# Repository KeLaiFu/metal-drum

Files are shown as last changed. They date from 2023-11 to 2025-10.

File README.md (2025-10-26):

This is a clone of a well known drum module, it has been tested, and with a few fixes, works fine.
The main issue is the transistors are 'flipped', this is due to the pin numbering being different between the THT and SMD versions within kicad. You can fix this by turning the transistor over and fitting it upside down. Theres one j111X component which doesnt have this problem and should be fitted as normal.

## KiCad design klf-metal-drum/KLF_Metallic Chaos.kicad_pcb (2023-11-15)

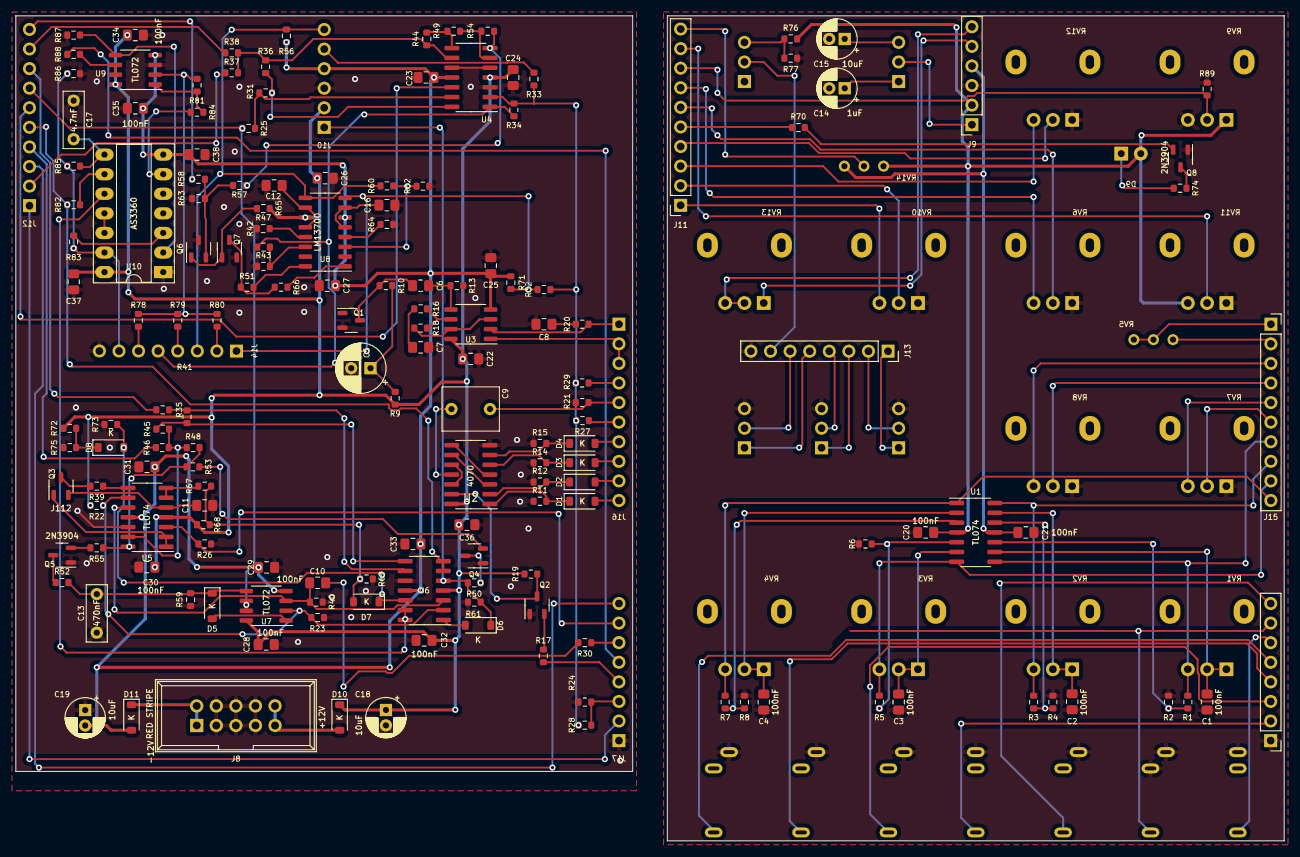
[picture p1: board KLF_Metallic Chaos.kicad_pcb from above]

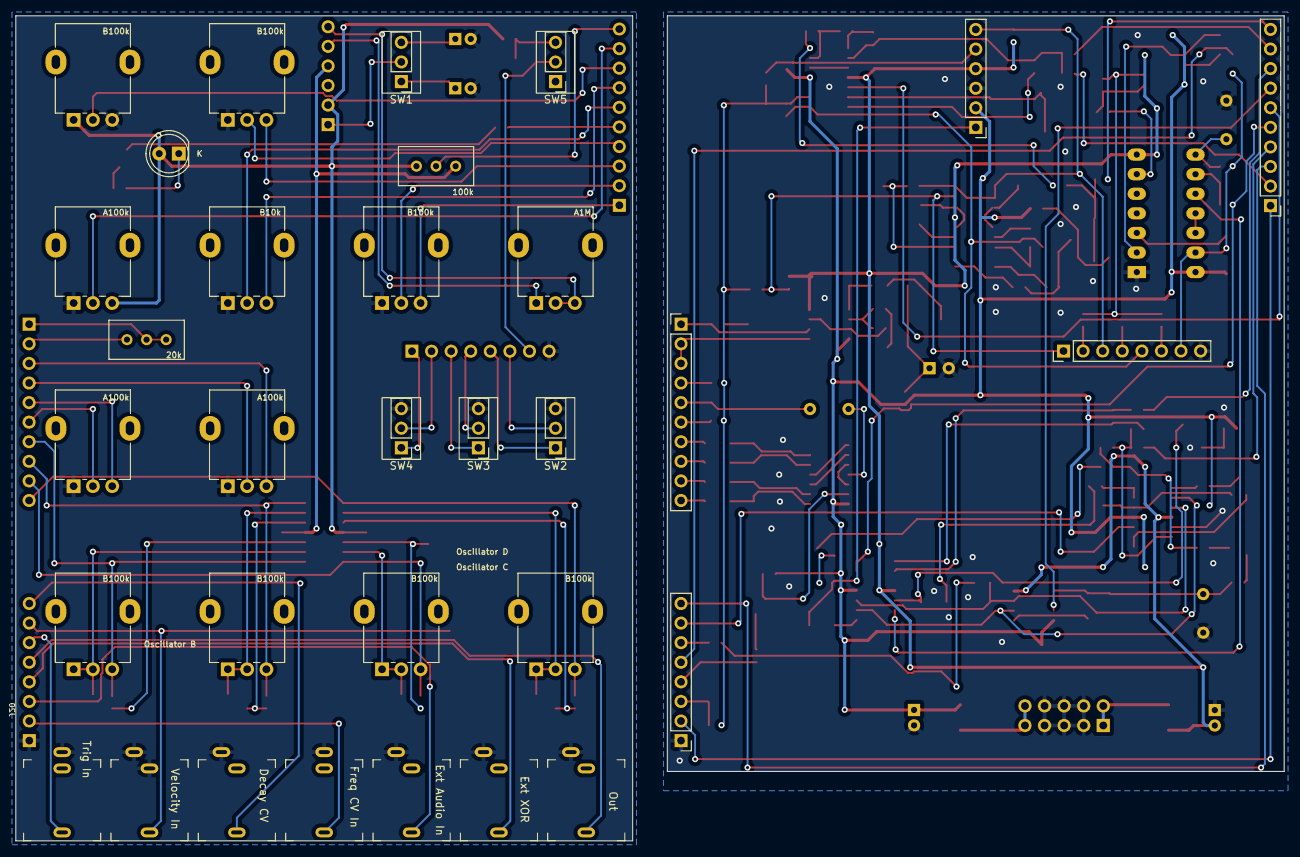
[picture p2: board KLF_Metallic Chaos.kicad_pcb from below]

Board: 2 copper layers, 164.5 x 107.0 mm, 193 parts (32 on the bottom side), 149 nets.

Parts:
C1, C2, C3, C4, C11, C20, C21, C22, C23, C24, C25, C26, C27, C28, C29, C30, C31, C32, C33, C34, C35, C36, C37, C38: 100nF; C_0805_2012Metric_Pad1.18x1.45mm_HandSolder
C5: 47uF; CP_Radial_D6.3mm_P2.50mm
C6, C10: 10nF; C_0805_2012Metric_Pad1.18x1.45mm_HandSolder
C7, C8: 220nF; C_0805_2012Metric_Pad1.18x1.45mm_HandSolder
C9: 1uF; C_Rect_L7.2mm_W5.5mm_P5.00mm_FKS2_FKP2_MKS2_MKP2
C12, C16: 150pF; C_0805_2012Metric_Pad1.18x1.45mm_HandSolder
C13: 470nF; C_Rect_L7.2mm_W2.5mm_P5.00mm_FKS2_FKP2_MKS2_MKP2
C14: 1uF; CP_Radial_D5.0mm_P2.00mm
C15, C18, C19: 10uF; CP_Radial_D5.0mm_P2.00mm
C17: 4.7nF; C_Rect_L7.2mm_W2.5mm_P5.00mm_FKS2_FKP2_MKS2_MKP2
D1, D2, D3, D4, D5, D6, D7, D8: 1N4148; D_SOD-123
D9: LED; LED_D5.0mm
D10, D11: 1N5817; D_SOD-123
J1: Ext XOR; PJ-301-M-12
J2: Freq CV In; PJ-301-M-12
J3: Ext Audio In; PJ-301-M-12
J4: Velocity In; PJ-301-M-12
J5: Trig In; PJ-301-M-12
J6: Decay CV; PJ-301-M-12
J7: Out; PJ-301-M-12
J8: Power_2x5; Power_Header
J9: Conn_01x06_Female; PinSocket_1x06_P2.54mm_Vertical
J10: Conn_01x06_Male; PinHeader_1x06_P2.54mm_Vertical
J11, J15: Conn_01x10_Female; PinSocket_1x10_P2.54mm_Vertical
J12, J16: Conn_01x10_Male; PinHeader_1x10_P2.54mm_Vertical
J13: Conn_01x08_Female; PinSocket_1x08_P2.54mm_Vertical
J14, J17, J20: Conn_01x08_Male; PinHeader_1x08_P2.54mm_Vertical
Q1: BC550; SOT-23-3
Q2, Q4, Q5, Q8: 2N3904; SOT-23-3
Q3: J112; SOT-23-3
Q6, Q7: 2N3906; SOT-23-3
R1, R3, R5, R7, R10, R11, R12, R13, R14, R15, R17, R18, R22, R24, R26, R27, R28, R29, R30, R32, R33, R34, R35, R37, R38, R40, R41, R44, R49, R54, R69, R73, R78, R79, R80, R81: 100k; R_0603_1608Metric
R2, R4, R6, R8, R45, R46, R48, R50, R51, R58, R65, R66, R70: 10k; R_0603_1608Metric
R9, R85, R89: 4.7k; R_0603_1608Metric
R16, R20, R23, R43, R47, R52, R62, R63, R64, R74, R88: 1k; R_0603_1608Metric
R19, R39, R53, R55, R59, R61: 1M; R_0603_1608Metric
R21: 1.5k; R_0603_1608Metric
R25, R31, R77: 20k; R_0603_1608Metric
R36, R68: 470k; R_0603_1608Metric
R42, R60: 200k; R_0603_1608Metric
R56, R71: 68k; R_0603_1608Metric
R57, R76, R82, R84, R87: 47k; R_0603_1608Metric
R67: 300k; R_0603_1608Metric
R72: 220k; R_0603_1608Metric
R75, R86: 30k; R_0603_1608Metric
R83: 15k; R_0603_1608Metric
RV1, RV2, RV3, RV4, RV9, RV10, RV12: B100k; Potentiometer_Alpha_RD901F-40-00D_Single_Vertical_centered
RV5: 20k; Potentiometer_Bourns_3296W_Vertical_screw_centered
RV6: B10k; Potentiometer_Alpha_RD901F-40-00D_Single_Vertical_centered
RV7, RV8, RV11: A100k; Potentiometer_Alpha_RD901F-40-00D_Single_Vertical_centered
RV13: A1M; Potentiometer_Alpha_RD901F-40-00D_Single_Vertical_centered
RV14: 100k; Potentiometer_Bourns_3296W_Vertical_screw_centered
SW1: Decay Short/Long; blue switch
SW2: HP; blue switch
SW3: BP; blue switch
SW4: LP; blue switch
SW5: VCA On/Off; blue switch
U1, U4, U5, U6: TL074; SO-14_3.9x8.65mm_P1.27mm
U2: 4070; SO-14_3.9x8.65mm_P1.27mm
U3, U7, U9: TL072; SO-8_3.9x4.9mm_P1.27mm
U8: LM13700; SO-16_3.9x9.9mm_P1.27mm
U10: AS3360; DIP-14_W7.62mm_Socket_LongPads

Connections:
+12V: C18.1, C20.2, C22.2, C24.2, C26.2, C28.2, C30.2, C32.2, C34.2, C36.2, C37.2, D9.2 (A), D10.1 (K), J9.2, J10.2, R9.2, R19.2, R22.2, R65.2, R68.2, R72.1, R76.2, RV9.1, RV11.3, RV14.1, U1.4 (V+), U2.14 (VDD), U3.8 (V+), U4.4 (V+), U5.4 (V+), U6.4 (V+), U7.8 (V+), U8.11 (V+), U9.8 (V+), U10.14 (VCC)
-12V: C19.2, C21.1, C23.1, C25.1, C27.1, C29.1, C31.1, C33.1, C35.1, C38.1, D11.2 (A), J9.4, J10.4, R56.1, R71.1, RV14.3, U1.11 (V-), U3.4 (V-), U4.11 (V-), U5.11 (V-), U6.11 (V-), U7.4 (V-), U8.6 (V-), U9.4 (V-), U10.7 (VEE)
BP2_A: J13.4, SW3.2 (B)
BP2_B: J14.4, R79.1
BP_A: J13.3, SW3.1 (A)
BP_B: J10.6, J14.3, R56.2, R60.1, U8.9
CVTrim_A: J11.10, RV14.2
CVTrim_B: J12.10, R58.1
Dec2_A: J11.8, R89.2, RV9.2
Dec2_B: J12.8, R35.1
DecCV_In_A: J11.3, RV12.3
DecCV_In_B: J6.T, J12.3, J17.decay_cv (Pin_8), J20.decay_cv (Pin_8)
Dec_A: J11.4, RV12.2
Dec_B: J12.4, R46.1
FilterCV: J12.7, R25.1, U7.6 (-), U7.7
FreqCV_A: J11.2, RV10.2
FreqCV_B: J12.2, R37.1
FreqCV_In_A: J11.1, RV10.3
FreqCV_In_B: J2.T, J12.1, J17.2, J20.2
FreqM1_A: J11.7, RV6.3
FreqM2_A: J11.6, RV6.2
FreqM2_B: J12.6, U4.12 (+)
Freq_A: J11.9, RV11.2
Freq_B: J12.9, R38.1
GND: C1.2, C2.2, C3.2, C4.2, C5.2, C7.2, C8.2, C11.2, C12.2, C13.1, C14.2, C15.2, C16.2, C17.1, C18.2, C19.1, C20.1, C21.2, C22.1, C23.2, C24.1, C25.2, C26.1, C27.2, C28.1, C29.2, C30.1, C31.2, C32.1, C33.2, C34.1, C35.2, C36.1, C37.1, C38.2, J1.S, J2.S, J3.S, J4.S, J4.TN, J5.S, J6.S, J7.S, J8.3, J8.4, J8.5, J8.6, J8.7, J8.8, J9.3, J10.3, J13.8, J14.8, J17.1, J20.1, Q1.2 (B), Q2.1 (E), Q4.1 (E), Q5.1 (E), Q6.3 (C), Q7.2 (B), Q8.1 (E), R2.1, R4.1, R6.1, R8.1, R11.1, R12.1, R13.1, R14.1, R15.1, R21.1, R23.1, R24.1, R26.1, R40.1, R43.1, R47.1, R59.1, R61.1, R62.1, R63.1, R64.1, R69.1, R73.1, R75.2, R77.1, R86.1, R87.1, R89.1, RV6.1, RV7.1, RV8.1, RV9.3, RV10.1, RV11.1, RV12.1, SW2.3 (C), SW3.3 (C), SW4.3 (C), U2.7 (VSS), U4.3 (+), U4.5 (+), U4.10 (+), U5.12 (+), U6.10 (+), U9.3 (+), U10.1 (GND)
HP2_A: J13.6, SW2.2 (B)
HP2_B: J14.6, R78.1
HP_A: J13.5, SW2.1 (A)
HP_B: J14.5, R34.2, R42.1, U4.1
LED_A: J11.5, R70.1
LED_B: J12.5, R82.1, U6.6 (-), U6.7
LP2_A: J13.2, SW4.2 (B)
LP2_B: J14.2, R80.1
LP_A: J13.1, SW4.1 (A)
LP_B: J14.1, R32.2, R71.2, U8.8
unnamed: C5.1, R9.1, R10.2
unnamed: C7.1, R16.1
unnamed: C8.1, R20.1
unnamed: C9.1, U2.11
unnamed: C10.1, R30.2
unnamed: C12.1, U8.10, U8.12
unnamed: C16.1, U8.5, U8.7
unnamed: D1.1 (K), R11.2, U2.1
unnamed: D2.1 (K), R12.2, U2.2
unnamed: D3.1 (K), R14.2, U2.5
unnamed: D4.1 (K), R15.2, U2.6
unnamed: D5.2 (A), U7.1
unnamed: C13.2, D5.1 (K), R52.2, R59.2, U7.5 (+)
unnamed: D6.2 (A), U6.1
unnamed: D7.2 (A), R67.2, R68.1, R69.2
unnamed: D7.1 (K), D8.2 (A), R73.2, U6.12 (+)
unnamed: D8.1 (K), R72.2, R75.1
unnamed: D9.1 (K), R74.2
unnamed: D10.2 (A), J8.9, J8.10
unnamed: D11.1 (K), J8.1, J8.2
unnamed: J1.T, J17.4, J20.4, R17.1
unnamed: J3.T, J17.3, J20.3, R24.2, R28.1
unnamed: J5.T, J17.6, J20.6, R30.1
unnamed: J7.T, J17.5, J20.5, R88.2
unnamed: C6.1, Q1.3 (E), R10.1
unnamed: Q2.2 (B), R17.2
unnamed: Q2.3 (C), R19.1, U2.13
unnamed: Q3.1 (D), U5.1, U5.2 (-)
unnamed: Q3.3 (G), R39.2
unnamed: C11.1, Q3.2 (S), U5.5 (+)
unnamed: Q4.2 (B), R53.2
unnamed: Q4.3 (C), R50.1
unnamed: Q5.2 (B), R55.2
unnamed: Q5.3 (C), R52.1
unnamed: Q6.2 (B), R57.2, R58.2, R63.2
unnamed: Q6.1 (E), Q7.1 (E), R65.1
unnamed: Q7.3 (C), R51.1, R66.1
unnamed: Q8.2 (B), R70.2
unnamed: Q8.3 (C), R74.1
unnamed: R31.2, R36.1, U4.14
unnamed: R39.1, U5.8
unnamed: R41.2, R45.1, U6.8
unnamed: R44.2, R49.1, U4.8
unnamed: R48.2, R53.1, R55.1, U5.14
unnamed: R51.2, U8.16
unnamed: R54.2, R57.1, U4.7
unnamed: R66.2, U8.1
unnamed: R81.2, R84.1, U9.1
unnamed: C14.1, SW1.1 (A)
unnamed: C15.1, SW1.3 (C)
unnamed: R76.1, R77.2, SW5.3 (C)
unnamed: R7.1, R8.2, U1.3 (+)
unnamed: C4.1, RV4.1, RV4.2, U1.2 (-)
unnamed: R5.1, R6.2, U1.5 (+)
unnamed: C3.1, RV3.1, RV3.2, U1.6 (-)
unnamed: R1.1, R2.2, U1.10 (+)
unnamed: C1.1, RV1.1, RV1.2, U1.9 (-)
unnamed: R3.1, R4.2, U1.12 (+)
unnamed: C2.1, RV2.1, RV2.2, U1.13 (-)
unnamed: U2.3, U2.9
unnamed: U2.4, U2.8
unnamed: U2.10, U2.12
unnamed: R18.1, U3.3 (+), U3.7
unnamed: C6.2, R13.2, U3.5 (+)
unnamed: R16.2, R18.2, U3.6 (-)
unnamed: R27.2, R28.2, R29.2, R32.1, R33.1, R34.1, U4.2 (-)
unnamed: R49.2, R54.1, U4.6 (-)
unnamed: R36.2, R37.2, R38.2, R44.1, U4.9 (-)
unnamed: R25.2, R31.1, U4.13 (-)
unnamed: J4.T, J17.7, J20.7, R26.2, U5.3 (+)
unnamed: R67.1, U5.6 (-), U5.7
unnamed: C10.2, R40.2, U5.10 (+), U6.3 (+), U7.3 (+)
unnamed: R45.2, R46.2, R48.1, U5.13 (-)
unnamed: R35.2, R41.1, U6.9 (-)
unnamed: R42.2, R43.2, U8.14 (+)
unnamed: R47.2, U8.13 (-)
unnamed: R60.2, R62.2, U8.3 (+)
unnamed: R64.2, U8.4 (-)
unnamed: R78.2, R79.2, R80.2, R81.1, U9.2 (-)
unnamed: R88.1, U9.6 (-), U9.7
unnamed: R84.2, U10.6 (II1)
unnamed: R87.2, U9.5 (+), U10.2 (IO1)
unnamed: R83.2, U10.3 (VE1)
unnamed: C17.2, R85.2, U10.8 (VREF)
unnamed: R82.2, U10.9 (II2)
unnamed: U6.13 (-), U6.14, U10.10 (VC2)
unnamed: U10.11 (VO2), U10.12 (VE2)
NoiseLvl1_A: J15.1, RV5.1, RV5.2
NoiseLvl1_B: J16.1, R20.2, U3.2 (-)
NoiseLvl2_A: J15.2, RV5.3
NoiseLvl2_B: J16.2, J16.3, U3.1
Noise_A: J15.3, RV8.3
Noise_Lvl_A: J15.4, RV8.2
Noise_Lvl_B: J16.4, R29.1
OSC1_A: J15.7, R1.2, RV1.3, U1.8
OSC1_B: D4.2 (A), J16.7
OSC2_A: J15.8, R3.2, RV2.3, U1.14
OSC2_B: D3.2 (A), J16.8
OSC3_A: J15.9, R5.2, RV3.3, U1.7
OSC3_B: D2.2 (A), J16.9
OSC4_A: J15.10, R7.2, RV4.3, U1.1
OSC4_B: D1.2 (A), J16.10
OSC_A: J15.5, RV7.3
OSC_B: C9.2, J16.5, R21.2
OSC_Lvl_A: J15.6, RV7.2
OSC_Lvl_B: J16.6, R27.1
Res1_A: J9.5, RV13.1
Res1_B: J10.5, R33.2
Res2_A: J9.6, RV13.2, RV13.3
Time_A: J9.1, SW1.2 (B)
Time_B: D6.1 (K), J10.1, R50.2, R61.2, U6.5 (+)
VCA_A: J13.7, SW5.2 (B)
VCA_B: J14.7, R83.1, R85.1, R86.2, U10.13 (IO2)
Vref: R22.1, R23.2, U5.9 (-), U6.2 (-), U7.2 (-)

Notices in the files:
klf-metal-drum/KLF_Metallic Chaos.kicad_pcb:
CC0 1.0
